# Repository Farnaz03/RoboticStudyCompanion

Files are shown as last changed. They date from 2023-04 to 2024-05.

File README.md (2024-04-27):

### All future development will be here: https://github.com/RobotStudyCompanion

# Robotic Study Companion (RSC)
A robotic study companion (RSC) is a type of social robot designed to interact with [university] students in a human-centric way and to operate in academic environments alongside them. RSCs can take on various forms, from humanoid to animal-like or even abstract, but they all share the goal of engaging students in an interpersonal manner. This involves communicating and coordinating their behaviour with students through various modalities, such as verbal, nonverbal, or affective means, with the aim of providing personalised support, feedback, and motivation for students to enhance their academic performance and learning outcomes.  
~_Farnaz Baksh, 2023_

**Thesis publication: [dSpace](https://dspace.ut.ee/handle/10062/93443)**  
**Youtube playlist of [RSC demos](https://youtube.com/playlist?list=PL49qLAAzGgOxQGmKcBarU2cArTEF4M34z)**

Link to thesis presentation: [google slides](https://docs.google.com/presentation/d/1bBWDUIlPUooCJXDMhWjwdlbGxtRz02nj1TfSVBF5hqg/edit?usp=sharing)  |  Video of practice presentation: [youtube](https://youtu.be/hVaGLehr0ZA) 

Answer this informal [RSC Survey](https://forms.gle/rxxPeKKdKfdqFwnz9)

## Design & Development
The RSC prototype is constructed using off-the-shelf components and utilised OpenAI's conversational API, which has proven its ability to simplify complex concepts and facilitate interactive conversations. The RSC features a portable, friendly hourglass shape design, standing at 11cm tall and weighing ~374g. 

To provide a comprehensive user experience, the RSC enables interaction through various modalities such as voice, gesture, tactile inputs, and incorporates visual, auditory, and motion indicators for enhanced expressiveness. It strikes a balance between cost and technical performance, making it affordable for educational institutions and students. 
With its sleek design and friendly appearance, the RSC can serve as an inviting and approachable study companion, offering academic support to students on their learning journey.

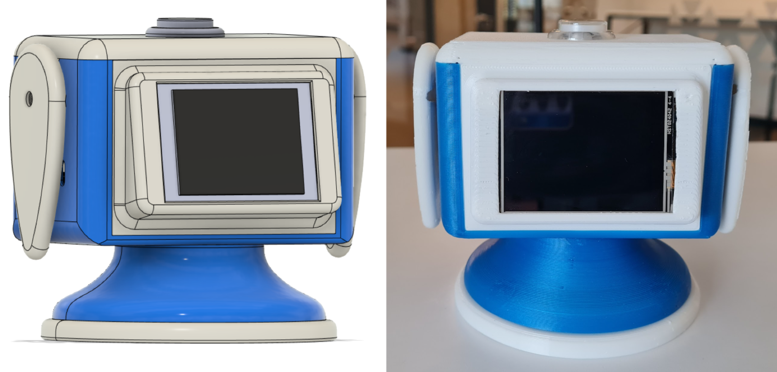
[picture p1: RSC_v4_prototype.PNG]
RSC_v4


### Hardware 
* RaspberryPi 4 Model B 4GB RAM + 32 GB SD Card
* AIY Voice Bonnet version2 (microphone + speaker + LED Button)
* Neopixel Ring 16 x 5050 RGB LED
* SG90 Servo Motors (Qty: 2)
*  Nextion Enhanced NX3224T024 - Generic 2.4'' HMI 320*240 Touch Display
*  Logic Level Shifter 4-Channel, Bidirectional

### Software
##### Raspbian GNU/Linux / AIY system image  

Current Libraries + Dependencies:
* AIY API library
* SpeechRecognition library version 3.9.0 
* pyttsx3 library version 2.90
* OpenAI Python Library version 0.27.4
* adafruit-circuitpython-neopixel library version 6.3.8

### To Do
- [ ]  try whisper & other TTS for natural voice
- [ ] create and implement touch display menu
- [ ] expand behavioural states

### Open Source License  
The Creative Commons Attribution-NonCommercial (CC BY-NC) license is an open-source license that allows others to use, distribute, and modify this project for non-commercial purposes as long as they give credit to the original author.

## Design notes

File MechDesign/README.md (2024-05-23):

# RSC MechDesign
CAD for RSC (Robotic Study Companion) version 1 developed in 2023.

Fusion360 archive file (assyv4 v67.f3z)  
Along with step files of all peripherals 



## Design File Summary

| Construction Part | File Name | Description | File Format |
|---|---|---|---|
| Rear panel | back_panel | Back sliding panel with ports for two power supplies. | STEP, 3MF, F3Z |
| Flipper | rsc_flipper | Side-mounted flipper for interaction with motion. | STEP, 3MF, F3Z |
| Front panel | LCD_panel | Front panel featuring HMI display. | STEP, 3MF, F3Z |
| Lid panel | button_neopx_panel | Lid with button and neopixel ring. | STEP, 3MF, F3Z |
| Speaker Base | speaker_base | Base shroud containing speaker. | STEP, 3MF, F3Z |
| Pi bracket | Pi_bracket_panel | Main bracket connecting panels and components. | STEP, 3MF, F3Z |

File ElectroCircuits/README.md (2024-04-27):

# RSC ElectroCircuits
Electronics Board info for RSC v1 (2023)

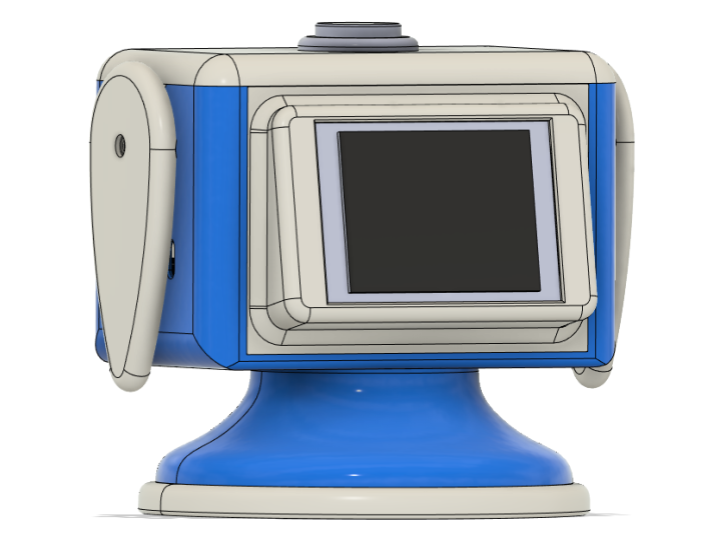
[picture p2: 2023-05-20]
MechDesign/cad_imgs/RSC_V4_2.png

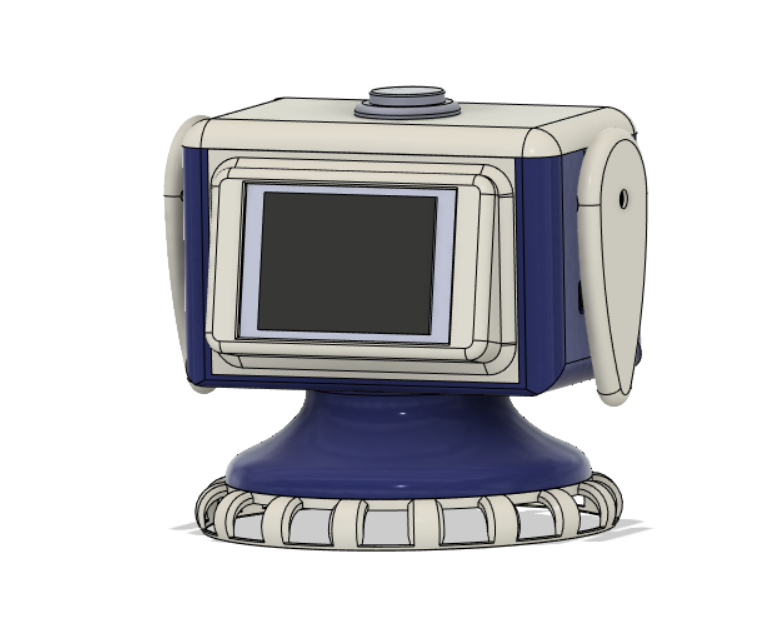
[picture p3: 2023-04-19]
MechDesign/cad_imgs/RSC_V4_1.png

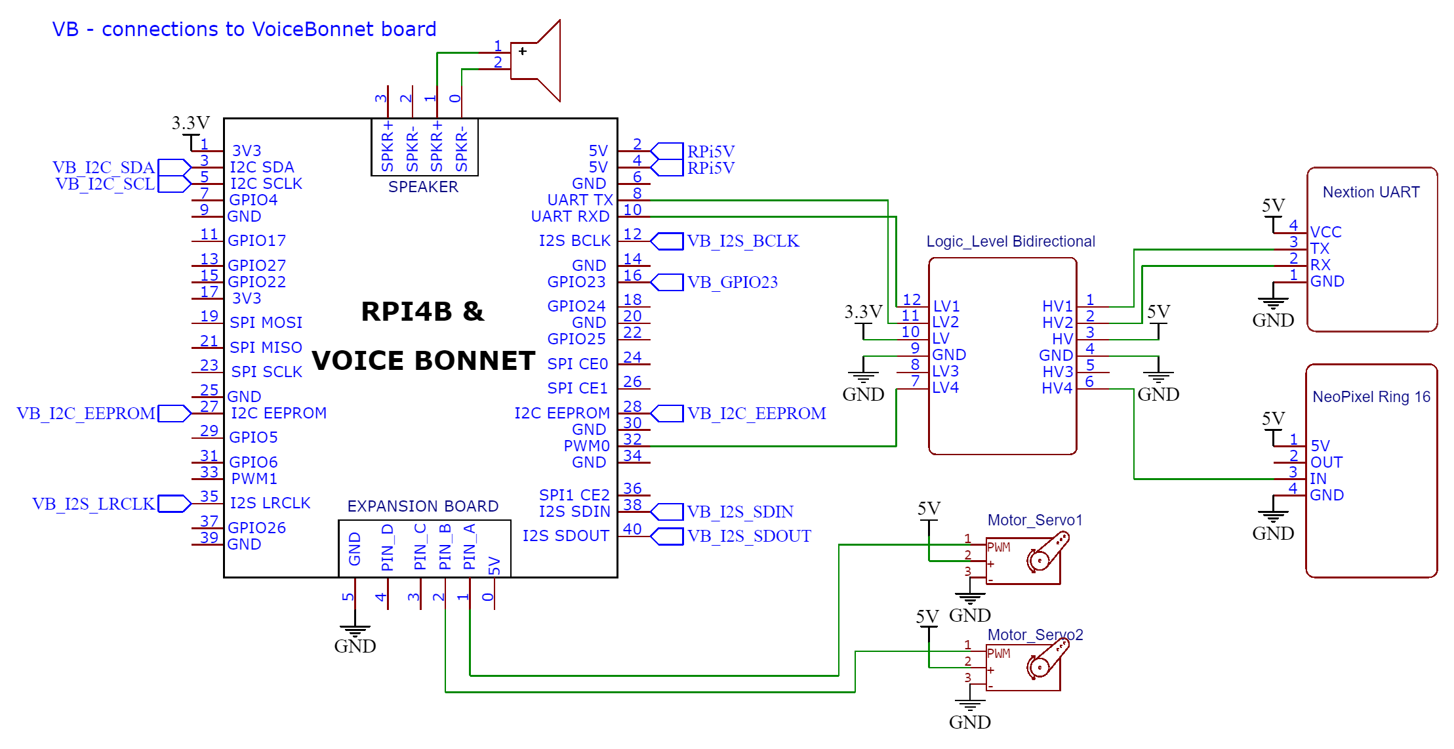
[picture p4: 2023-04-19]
ElectroCircuits/Schematic_RSC_breakout_board_2023-04-17.png

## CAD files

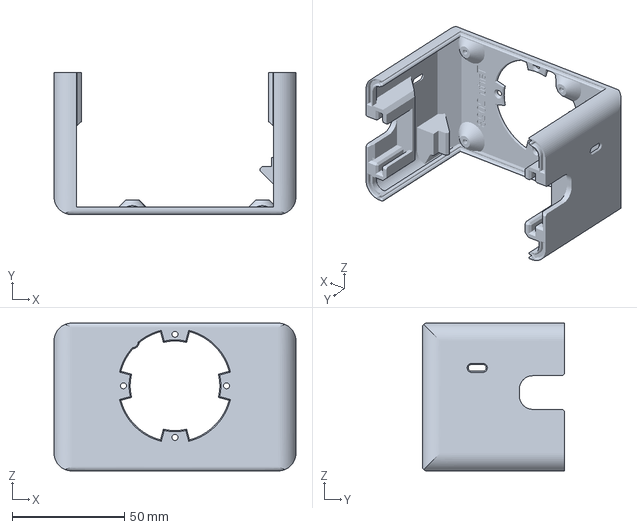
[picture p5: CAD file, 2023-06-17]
MechDesign/3mf_files_v4_2/Pi_bracket_panel.3mf
108.0 x 63.5 x 66.0 mm

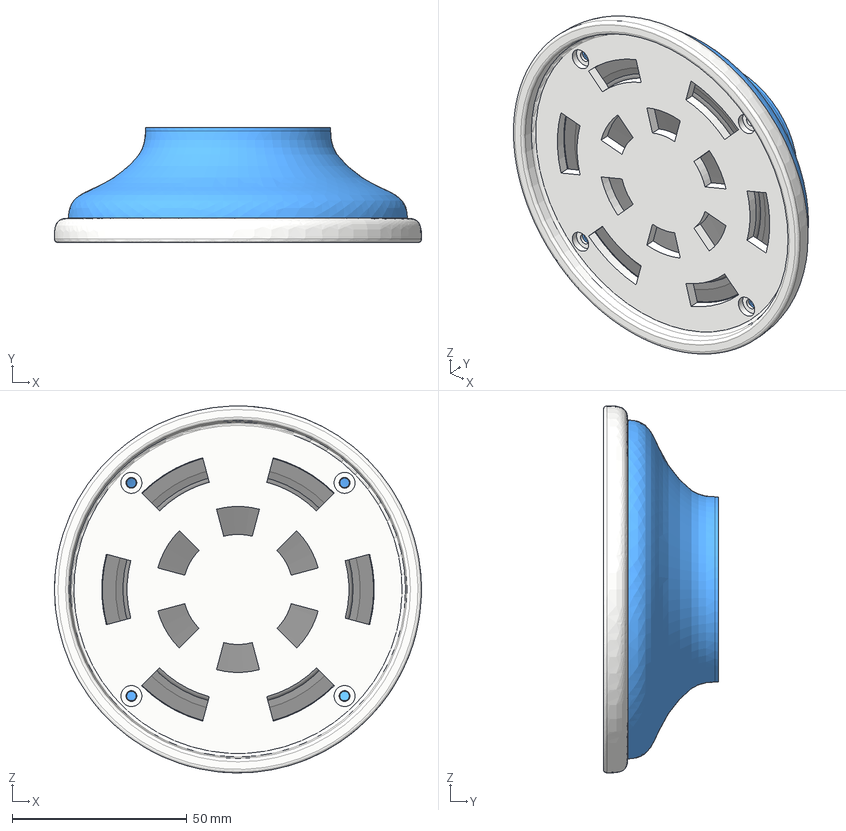
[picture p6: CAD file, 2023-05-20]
MechDesign/speaker_base v40.step
105.0 x 33.0 x 105.0 mm
base_speaker
base2_speaker

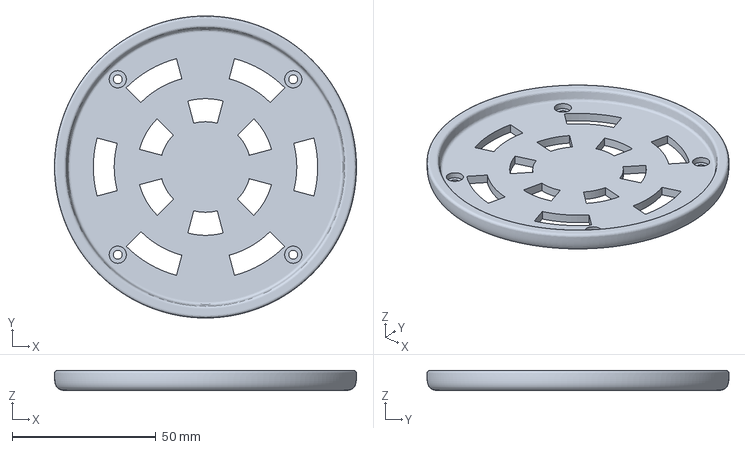
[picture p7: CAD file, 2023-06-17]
MechDesign/3mf_files_v4_2/speaker_basev3.3mf
105.0 x 105.0 x 7.00 mm

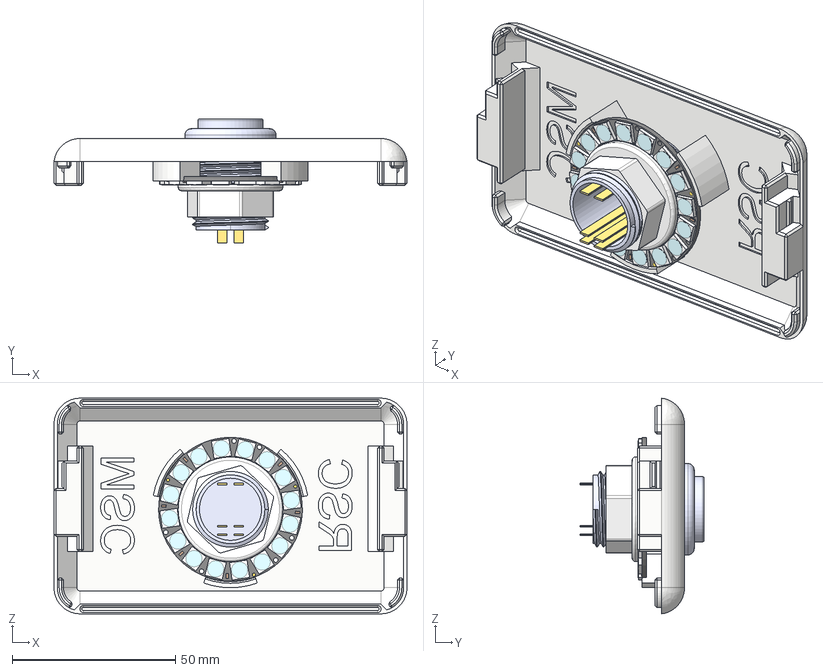
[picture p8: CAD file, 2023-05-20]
MechDesign/button_neopx_panel v77.step
108.0 x 38.0 x 66.0 mm
Arcade_PushButton
NeoPixelRing16
ButtonLock_Nut

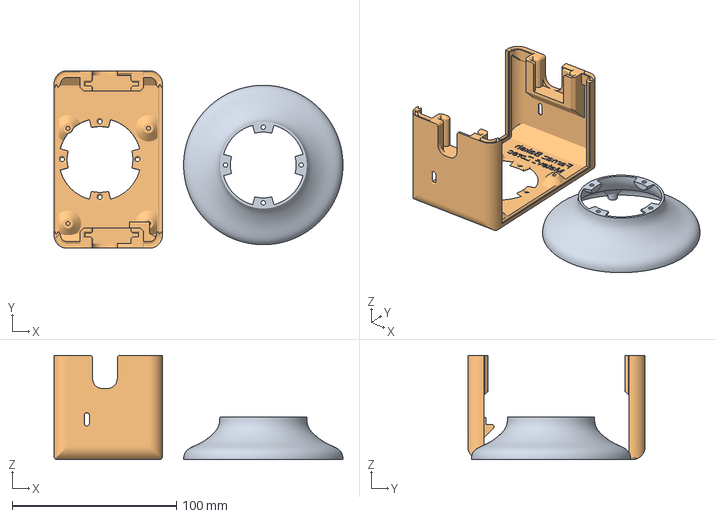
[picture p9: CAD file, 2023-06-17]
MechDesign/3mf_files_v4_2/pi_bracket_speaker_shroud.3mf
175.9 x 108.0 x 63.5 mm
speaker_shroud
Pi_bracket_panel

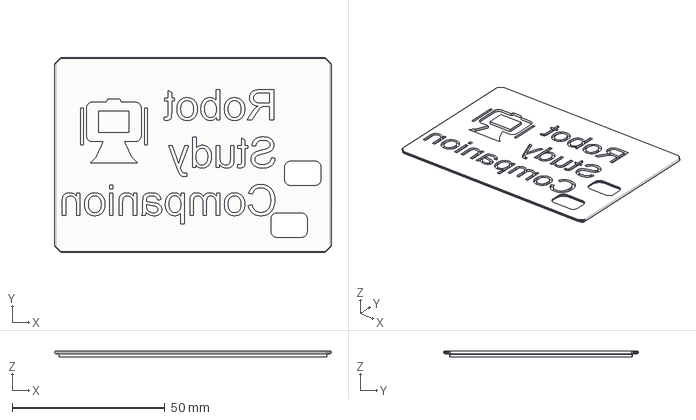
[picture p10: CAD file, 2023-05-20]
MechDesign/back_panel v39.step
90.8 x 63.8 x 1.95 mm

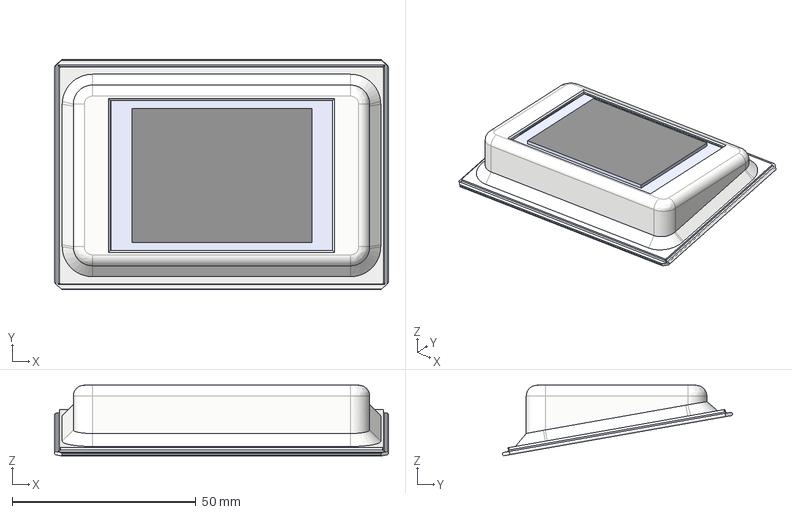
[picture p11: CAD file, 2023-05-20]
MechDesign/LCD_panel v63.step
90.8 x 62.6 x 19.2 mm

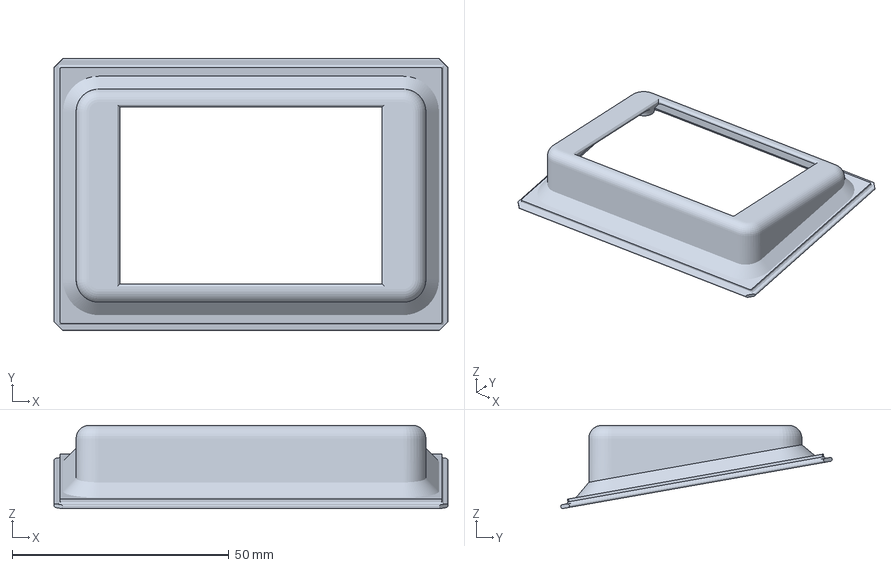
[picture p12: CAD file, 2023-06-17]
MechDesign/3mf_files_v4_2/LCD_panel.3mf
90.8 x 62.6 x 19.2 mm

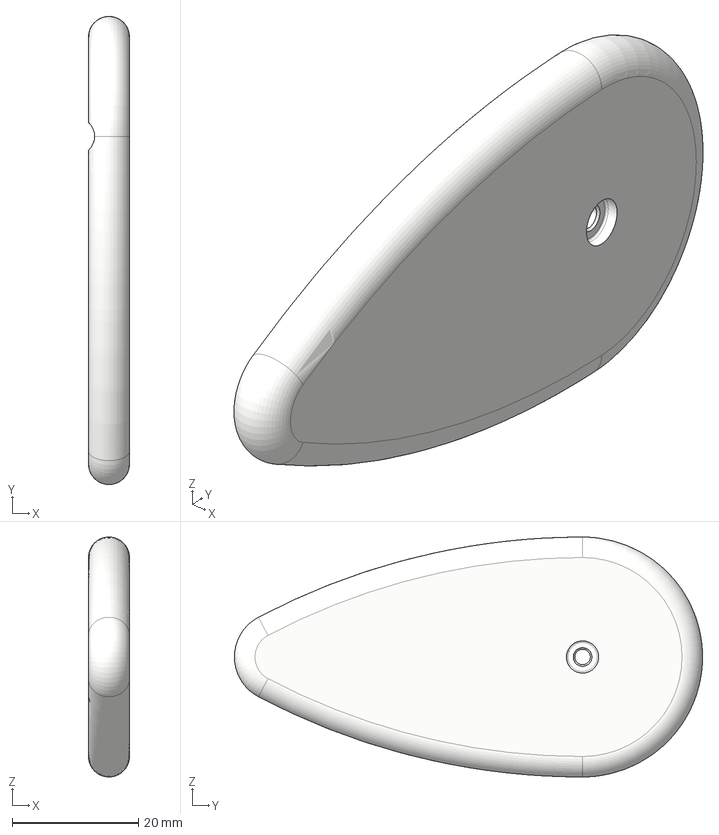
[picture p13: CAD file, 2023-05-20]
MechDesign/rsc_flipper v8.step
6.50 x 74.1 x 38.0 mm

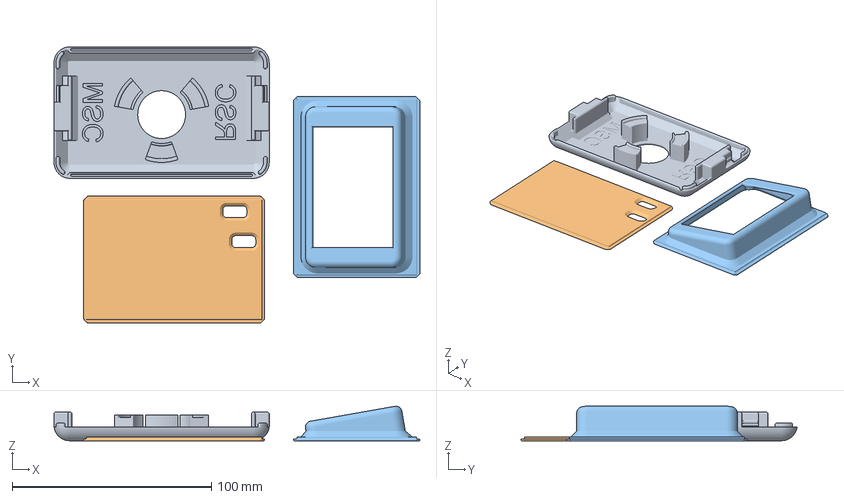
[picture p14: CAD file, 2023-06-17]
MechDesign/3mf_files_v4_2/lcd_back_top_panels.3mf
183.6 x 138.6 x 17.4 mm
button_neopx_panel
back_panel
LCD_panel

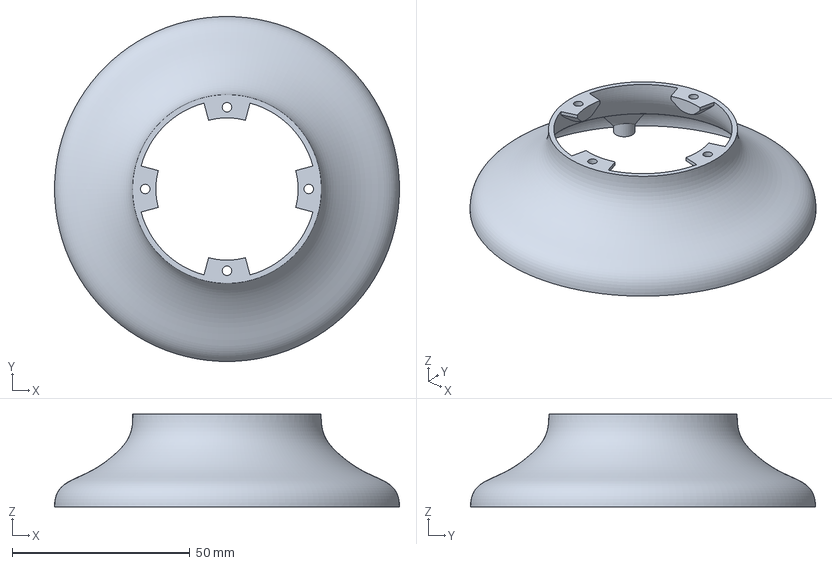
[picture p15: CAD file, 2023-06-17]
MechDesign/3mf_files_v4_2/speaker_shroud.3mf
97.0 x 97.0 x 26.1 mm

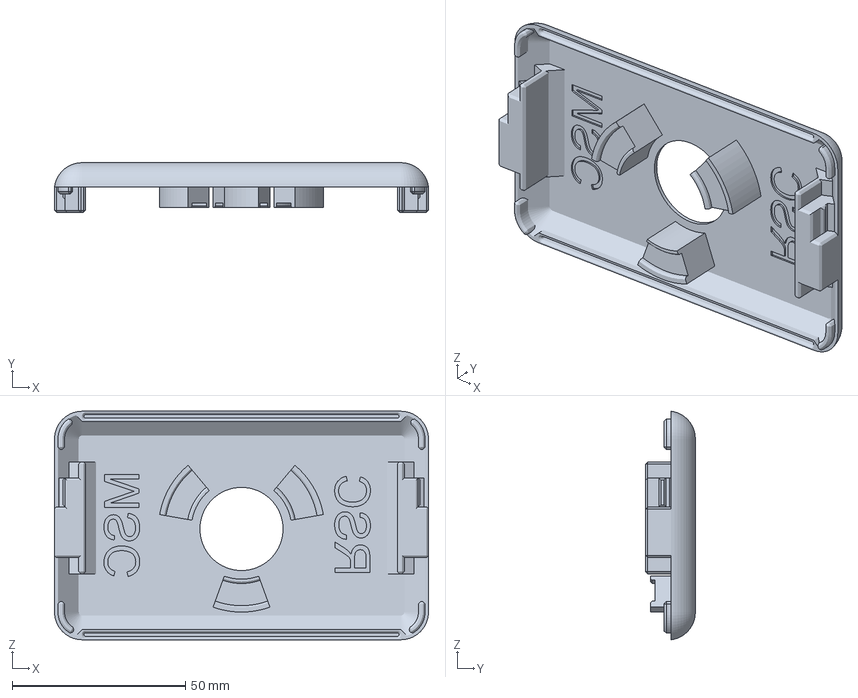
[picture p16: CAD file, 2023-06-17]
MechDesign/3mf_files_v4_2/button_neopx_panel.3mf
108.0 x 14.3 x 66.0 mm

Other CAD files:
MechDesign/3mf_files_v4_2/back_panel.3mf

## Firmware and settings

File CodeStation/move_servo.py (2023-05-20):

# https://aiyprojects.withgoogle.com/voice/#makers-guide--gpio-expansion-pins

from gpiozero import Servo
from aiy.pins import PIN_A
from aiy.pins import PIN_B
import time

def wave_hi():
    # Create a servo with the custom values to give the full dynamic range.
    tuned_servo = Servo(PIN_A, min_pulse_width=.0005, max_pulse_width=.0019)
    tuned_servo1 = Servo(PIN_B, min_pulse_width=.0005, max_pulse_width=.0019)
    
    # Move the Servo to wave hi.
    tuned_servo.value = 1  # Set the servo angle to 90 degrees.
    time.sleep(0.5)
    # tuned_servo1.value = -1
    # time.sleep(0.5)
    tuned_servo.value = None  # Set the servo angle to neutral.

if __name__ == '__main__':
    wave_hi()

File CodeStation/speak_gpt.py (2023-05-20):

import openai
import pyttsx3
import speech_recognition as sr
from openai_key import API_KEY

import move_servo

import time
import light_neopixel
print("Ready to go ... ")
# #NeoPixel = GREEN = Ready to listen
light_neopixel.pixels.fill((0, 255, 0))
light_neopixel.pixels.show()
time.sleep(5)

openai.api_key = API_KEY

engine = pyttsx3.init()
engine.setProperty('volume', 0.5)

r = sr.Recognizer()
mic = sr.Microphone(device_index=1) 
# write script to find device index
#mic = sr.Microphone()

conversation = ""
user_name = "Farnaz"
bot_name = "Robot Study Companion"

# engine.say("Hello, I am your RSC, Robot Study Companion. How may I help you?")

#Wave Hi
move_servo.wave_hi()
print("waving Hi!")
time.sleep(2)

while True:
    with mic as source:
        print("\nlistening...")
        engine.say("I am listening")
        r.adjust_for_ambient_noise(source, duration=0.1) #background noise
        try:
            audio = r.listen(source, timeout=5) #set timeout to 5 seconds
        except sr.WaitTimeoutError:
            print("Microphone is not picking up any sound. Please check your microphone and try again.")
            continue
    print("no longer listening.\n")

    try:
        user_input = r.recognize_google(audio)
    except Exception as e:
        print(f"\nException occurred!:\n{e}\n")
        continue

    prompt = user_name + ": " + user_input + "\n" + bot_name+ ": "

    conversation += prompt  # allows for context

    # fetch response from open AI api
    response = openai.Completion.create(engine='text-davinci-003', prompt=conversation, max_tokens=300)
    response_str = response["choices"][0]["text"].replace("\n", "")
    # response_str = response_str.split(user_name + ": ", 1)[0].split(bot_name + ": ", 1)[0]

    # conversation += response_str + "\n"
    # print(response_str)

    response_lines = response_str.split("\n")
    response_str = ""
    for line in response_lines:
        if user_name + ":" not in line and bot_name + ":" not in line:
            response_str += line.strip()

    conversation += bot_name + ": " + response_str + "\n"
    print(bot_name + ": " + response_str)
    
    engine.say(response_str)
    engine.runAndWait()

        # Turn off all LEDs
    light_neopixel.pixels.fill((0, 0, 0))
    light_neopixel.pixels.show()
    print("okay, bye ...")

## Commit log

2023-05-20 CAD files
    [LCD_panel v63.step, back_panel v39.step, button_neopx_panel v77.step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]
2023-06-17 3mf files for v4.2
    [LCD_panel.3mf, Pi_bracket_panel.3mf, back_panel.3mf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]
2024-05-23 Add BOM (v3)
2024-05-23 fix BOM table
